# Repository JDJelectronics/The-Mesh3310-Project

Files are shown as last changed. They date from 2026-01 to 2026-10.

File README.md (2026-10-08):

# The-Mesh3310-Project
Make the world's strongest node.

## 📱 Mesh3310: The Ultimate Off-Grid Communicator
Mesh3310 is an open-source hardware project that revives the legendary Nokia 3310 (Classic). It replaces the obsolete 2G internals with a modern, high-performance PCB.

The goal is to turn this indestructible icon into a rugged, long-range mesh networking node that runs **Meshtastic** and **MeshCore**.

<p align="center">
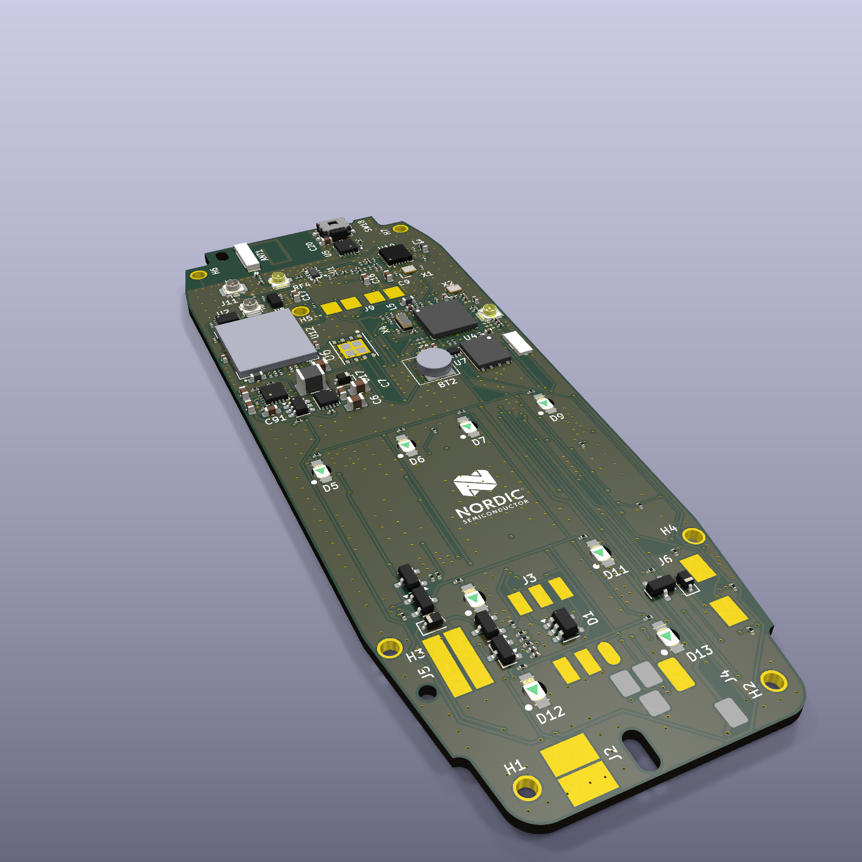
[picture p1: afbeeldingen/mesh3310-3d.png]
Mesh3310 PCB, 3D view
  
</p>

## 🚀 The Vision
The Nokia 3310 is famous for its durability, tactile keypad and ergonomic design. Our custom board drops straight into the original housing and gives the phone a second life as a decentralized communicator that does not rely on cell towers or the internet. When a network *is* available, the built-in LTE modem can connect the mesh to the rest of the world.

## ⚡ Key Specifications
| Function | Part |
|---|---|
| MCU | Nordic **nRF52840** (Cortex-M4F, Bluetooth LE, USB) |
| LoRa | Semtech **SX1262** with a Skyworks SKY65723 front-end; on-board chip antenna in the original antenna area |
| Cellular / GNSS | Nordic **nRF9151** (LTE-M / NB-IoT, DECT NR+, GNSS); antennas via U.FL |
| Bluetooth antenna | On-board 2.4 GHz chip antenna |
| Power | TI BQ24074 charger + TPS63031 buck-boost, original 3310 battery contacts |
| Charging / USB | Through the original bottom connector (USB data to the nRF52840) |
| Display / input | Original PCD8544 monochrome LCD, full keypad with backlight, side power button |
| Audio | MAX98357A amplifier for the speaker, microphone, buzzer and vibration motor contacts |
| Storage | 2 × 16 Mbit flash (MX25R1635F), one for each Nordic chip |
| Firmware | Built to run Meshtastic and MeshCore |

## 🛠 Project Status: Rev. A layout complete 🏗️
- The schematic is complete and passes ERC.
- The **6-layer PCB** (JLCPCB stackup JLC06161H-3313) is fully routed, passes DRC and matches the schematic.
- Board outline, mounting holes, battery contacts, display, SIM, speakers, keypad and backlight LEDs match the original Nokia 3310 housing.
- Controlled-impedance RF lines (50 Ω) and a solid ground plane under all three radios.
- Every assembled part has an **LCSC part number**, ready for JLCPCB assembly.

Next steps: order the first prototypes, tune the RF matching networks and start firmware bring-up.

| Top | Bottom (keypad side) |
|---|---|
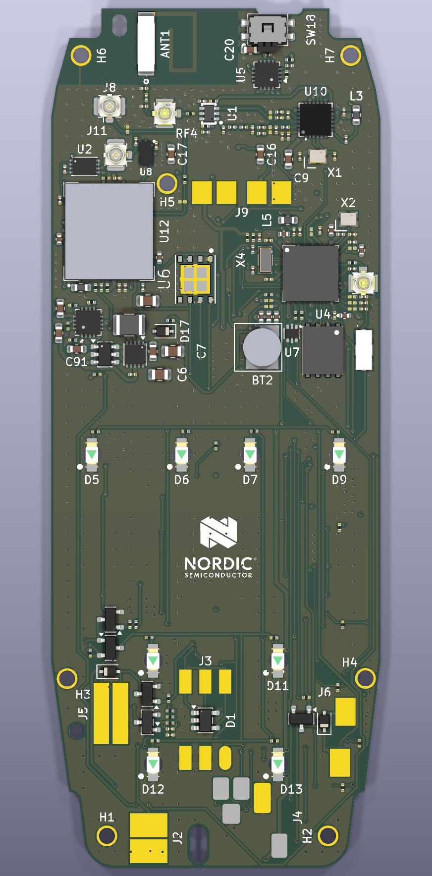
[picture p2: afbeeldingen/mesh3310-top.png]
Top side
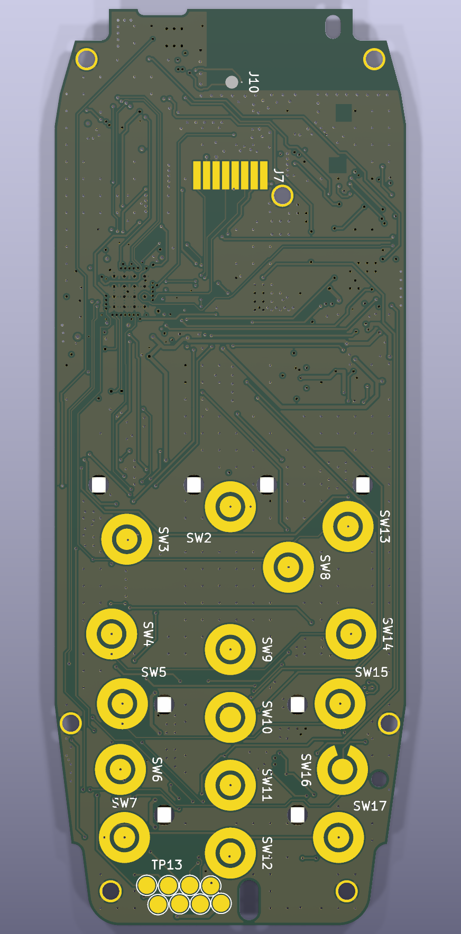
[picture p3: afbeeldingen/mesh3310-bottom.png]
Bottom side
|  |  |

## 📂 Repository Layout
| Folder | Contents |
|---|---|
| `Kicad_Mesh3310/` | KiCad 9 project (schematic, PCB, libraries, 3D models) |
| `Kicad_Mesh3310/datasheets/` | Datasheets of the main components |
| `productie/` | Gerbers, drill files, pick-and-place file and BOM (JLCPCB format), plus manufacturing notes (Dutch) |
| `afbeeldingen/` | Renders of the board |

## 🤝 How You Can Help
We are actively looking for contributors. Your input can directly shape the hardware.

- **Hardware engineering**: review the schematic and layout, and help with RF tuning.
- **Firmware development**: port Meshtastic/MeshCore to the legacy LCD and keypad matrix.
- **Mechanical design**: check the fit in original and replacement shells, and design internal 3D-printed parts.

## 💬 Community & Contributing
Most of the coordination happens on Discord.

Join our Discord: https://discord.gg/E6Sk9hmUE

### Concept images
Schermafbeelding 2026-02-24 191950



## License
MIT

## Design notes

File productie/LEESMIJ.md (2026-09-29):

# Mesh3310 — productie-opmerkingen (rev. A, 29-09-2026)

## Bestellen bij JLCPCB
- **6 lagen, opbouw JLC06161H-3313**, 1,6 mm, ENIG.
  | Laag | Functie |
  |---|---|
  | F.Cu | onderdelen, RF (50 Ω CPWG: 0,14 mm spoor, 0,30 mm spleet) |
  | In1 | doorlopend GND (referentie RF, 0,0994 mm onder F.Cu) |
  | In2 | signalen |
  | In3 | doorlopend +3V3-vlak |
  | In4 | signalen |
  | B.Cu | toetsenbord, displayconnector, GND-vulling |
- **Impedantiecontrole** aanvragen: 50 Ω enkelzijdig op F.Cu (ref. In1), 90 Ω differentieel USB (0,15/0,12 mm).
- **Via-in-pad gevuld en afgedekt (POFV/epoxy + cap)** is nodig: via's in de toets-middenpads (contactvlak onder de rubberen dome), in binnenste nRF52840-pads (aQFN-73) en in enkele kleine GND-pads.
- Kleinste maten: spoor/ruimte 0,10 mm (aQFN-uitlopen, enkele segmenten), via 0,30/0,15 mm (14 stuks), meestal 0,45/0,25 mm.

## Bestanden
- `gerber/` — 13 lagen + PTH/NPTH-boorbestanden + boorkaart + job-bestand
- `Mesh3310-positie.csv` — positiebestand (zonder DNP)
- `Mesh3310-stuklijst.csv` — stuklijst in JLC-formaat (Comment, Designator, Footprint, LCSC), zonder DNP

Opnieuw maken: exporteer vanuit KiCad 9 (Plot + Drill Files, Position Files en Bill of Materials).

## Onderdelen (LCSC)
- Alle geplaatste onderdelen hebben een LCSC-nummer (veld `LCSC` in het schema). Zonder nummer: alleen pads/behuizingsdelen (SIM J3, J4, testpunten) en BT2.
- Keuze: op voorraad (≥ 500), dan basic > preferred > extended, dan de laagste prijs. 12 basic en 72 extended soorten; onderdelen ~$46 per bord (vooral nRF9151 $17 en nRF52840 $6). Elk extended-onderdeel kost bij JLC ~$3 laadkosten per order; de meeste zijn 0201-passieven (die zijn bij JLC nooit basic).
- **Weinig voorraad** (vóór bestellen checken): SW18 C128539 (27 st.), U8 SKY65723 C2654196 (~330), U3 BQ24074 C54313 (~440), C77 C881877 (~875).
- **BT2** (ML414H knoopcel-accu) staat niet in de stuklijst (`in_bom no`) en is niet bij LCSC te krijgen; zelf plaatsen of weglaten (voedt alleen P0.26).
- Aangepast: C16/C17 van tantaal naar keramisch 0603 (C19702 10 µF, C59461 22 µF); X4 32,768 kHz met 9 pF laadcapaciteit (C97605), past bij C22/C29 van 15 pF.
- Datasheets van alle actieve en bijzondere onderdelen: `Kicad_Mesh3310/datasheets/` (van de nRF9151 alleen de productbrief; de volledige specificatie staat op docs.nordicsemi.com).

## Controle
- ERC: 0 fouten. DRC: 0 fouten, 0 onverbonden, pariteit schema ↔ bord 0.
- Nagelopen: voedings- en signaalverbindingen in de netlijst, behuizingsonderdelen en bordrand ongewijzigd t.o.v. main, GND- en +3V3-vlak doorlopend, RF-sporen zonder via's, voedingssporen ≥ 0,4 mm.
- Bewuste uitzonderingen (in `Mesh3310.kicad_dru` / projectbestand, met toelichting):
  ANT1-antennepatroon (netloos koper), BLE-antennepin nRF52840 (0,15 mm bij de pin),
  testmal-testpunten (courtyards), backlight-LED's in eigen uitsparing, aangepaste footprints (waarschuwing).

## Programmeren
- nRF52840: SWD via de testpunten van de testmal (SWDIO/SWDCLK/RESET/SWO).
- nRF9151: R10/R28 (0R naar de gedeelde SWD-lijnen) zijn standaard **niet geplaatst**. Twee SWD-chips op dezelfde lijnen werkt niet; de nRF9151 programmeren via de pads van R10/R28 (kant U12) of de 0R's tijdelijk plaatsen.

## Nog te doen / aandachtspunten
- **RF afstemmen** met de echte antennes en kabels: LTE-pi-netwerk R61/C93/C94 (shunts nu DNP), LoRa en BLE volgens het oorspronkelijke ontwerp.
- **LTE-antenne**: plak-flexantenne via U.FL J8 (bv. Taoglas FXUB63); GNSS-antenne via U.FL J11.
- **Montagegat H6** ligt in de LoRa-antennezone en is aan GND gehangen (kort spoor langs de zonerand); eventueel los laten na meting.
- **Bouwhoogte** van U.FL-connectoren J8/J11 (+ stekker) controleren in de behuizing.
- Referenties van kleine passieven staan niet op de zeefdruk (wel op de Fab-laag / in het positiebestand).

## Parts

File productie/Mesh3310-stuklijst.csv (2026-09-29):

Comment | Designator | Footprint | LCSC
0868AT43A0020E | ANT1 | mesh3310_footprints:XCVR_0868AT43A0020E | C3284550
2450AT42E0100001E | ANT2 | mesh3310_footprints:2450AT42E0100001E | C17605137
1uF | C9 | Capacitor_SMD:C_0603_1608Metric | C15849
33pF | C15 | Capacitor_SMD:C_0201_0603Metric | C384825
22uF/6.3V | C17 | Capacitor_SMD:C_0603_1608Metric | C59461
470nF | C19 | Capacitor_SMD:C_0201_0603Metric | C7393835
47uF/6.3V | C28 | Capacitor_SMD:C_0805_2012Metric | C16780
2.0pF | C30 | Capacitor_SMD:C_0201_0603Metric | C301906
1uF | C36 | Capacitor_SMD:C_0402_1005Metric | C52923
100pF | C45 | Capacitor_SMD:C_0201_0603Metric | C62550
820pF | C46 | Capacitor_SMD:C_0201_0603Metric | C18164584
47pF | C77 | Capacitor_SMD:C_0201_0603Metric | C881877
2.4pF | C78 | Capacitor_SMD:C_0201_0603Metric | C1853504
3pF | C81 | Capacitor_SMD:C_0201_0603Metric | C501815
5.6pF | C82 | Capacitor_SMD:C_0201_0603Metric | C526923
39pF | C83 | Capacitor_SMD:C_0201_0603Metric | C285092
1uF/25V | C89 | Capacitor_SMD:C_0603_1608Metric | C15849
100nF | C1,C13,C34,C41,C58,C69 | Capacitor_SMD:C_0201_0603Metric | C408130
15p | C11,C26 | Capacitor_SMD:C_0201_0603Metric | C5142550
10uF/10V | C16,C20,C92 | Capacitor_SMD:C_0603_1608Metric | C19702
0.1u | C2,C4,C10,C12,C33,C43 | Capacitor_SMD:C_0201_0603Metric | C408130
15pF | C22,C29 | Capacitor_SMD:C_0201_0603Metric | C5142550
4.7u | C3,C8 | Capacitor_SMD:C_0402_1005Metric | C23733
12pF | C31,C32 | Capacitor_SMD:C_0201_0603Metric | C50391
2.2uF | C35,C37,C39,C40,C47,C50 | Capacitor_SMD:C_0402_1005Metric | C107370
47nF | C38,C76 | Capacitor_SMD:C_0201_0603Metric | C301920
100n | C5,C14,C18,C21,C27 | Capacitor_SMD:C_0201_0603Metric | C408130
22uF/10V | C6,C7 | Capacitor_SMD:C_0805_2012Metric | C45783
10pF | C70,C71 | Capacitor_SMD:C_0201_0603Metric | C387913
1.8pF | C75,C84 | Capacitor_SMD:C_0201_0603Metric | C22374841
1nF | C85,C86 | Capacitor_SMD:C_0201_0603Metric | C66942
3.6pF | C87,C88 | Capacitor_SMD:C_0201_0603Metric | C301911
4.7uF/10V | C90,C91 | Capacitor_SMD:C_0603_1608Metric | C19666
SP0504BAHT | D1 | Package_TO_SOT_SMD:SOT-23-5 | C19829475
BAT60A | D4,D8,D17 | Diode_SMD:D_SOD-323 | C5355496
RED | D5,D6,D7,D9,D10,D11,D12,D13 | mesh3310_footprints:3310_led | C2827254
120R@100MHz 1A | FB1 | Inductor_SMD:L_0603_1608Metric | C14709
Sim/Pad | J3 | mesh3310_footprints:3310_sim
Conn_01x05_Pin | J4 | mesh3310_footprints:3310_dc
LTE antenne: U.FL -> flexantenne (bv. Taoglas FXUB63) | J8 | Connector_Coaxial:U.FL_Hirose_U.FL-R-SMT-1_Vertical | C88374
GNSS antenne (U.FL) | J11 | Connector_Coaxial:U.FL_Hirose_U.FL-R-SMT-1_Vertical | C88374
3.3nH | L1 | Inductor_SMD:L_0201_0603Metric | C42144
1u5 | L2 | Inductor_SMD:L_1210_3225Metric | C113080
15uH | L3 | Inductor_SMD:L_0603_1608Metric | C486329
1.5nH | L4 | Inductor_SMD:L_0201_0603Metric | C54929554
10uH | L5 | Inductor_SMD:L_0603_1608Metric | C1035
0 | L15 | Inductor_SMD:L_0201_0603Metric | C473473
47nH | L16 | Inductor_SMD:L_0201_0603Metric | C46607399
2.5nH | L17 | Inductor_SMD:L_0201_0603Metric | C52109745
4.7nH | L18 | Inductor_SMD:L_0201_0603Metric | C52109761
8.2nH | L19 | Inductor_SMD:L_0201_0603Metric | C52109772
15nH | L6,L13 | Inductor_SMD:L_0201_0603Metric | C52109780
BC847 | Q1 | Package_TO_SOT_SMD:SOT-23 | C57668
IRLML6401 | Q6 | Package_TO_SOT_SMD:SOT-23 | C22363750
BSS138 | Q4,Q5,Q7 | Package_TO_SOT_SMD:SOT-23 | C518792
1.8k | R5 | Resistor_SMD:R_0201_0603Metric | C473538
33R | R8 | Resistor_SMD:R_0201_0603Metric | C423356
2.2k | R9 | Resistor_SMD:R_0201_0603Metric | C171950
1M | R14 | Resistor_SMD:R_0201_0603Metric | C473450
56R | R16 | Resistor_SMD:R_0201_0603Metric | C49654370
220k | R36 | Resistor_SMD:R_0201_0603Metric | C49653410
100k | R15,R17,R20,R37,R51 | Resistor_SMD:R_0201_0603Metric | C3152012
47k | R18,R31,R32,R33,R34,R35,R59,R60 | Resistor_SMD:R_0201_0603Metric | C304544
150R | R19,R21,R22,R23,R24,R25,R26,R27 | Resistor_SMD:R_0201_0603Metric | C49653085
0 | R3,R38,R57,R58 | Resistor_SMD:R_0201_0603Metric | C473473
1k | R4,R13,R29,R52 | Resistor_SMD:R_0201_0603Metric | C3152043
100 | R44,R45 | Resistor_SMD:R_0201_0603Metric | C3152013
0R | R6,R61 | Resistor_SMD:R_0201_0603Metric | C473473
10k | R7,R11,R12,R30 | Resistor_SMD:R_0201_0603Metric | C3152038
A-IPEX1-1.25A | RF3,RF4 | mesh3310_footprints:IPEX-SMD_3P-L2.6-W2.6-LS3.0_RF1200001R | C22467595
POWER ON/OFF | SW18 | mesh3310_footprints:SIDE PUSH 2.2NF 4.7x3.2x1.65mm | C128539
VBUS | TP9 | TestPoint:TestPoint_Pad_D2.0mm
GND | TP10 | TestPoint:TestPoint_Pad_D2.0mm
USB_D- | TP11 | TestPoint:TestPoint_Pad_D2.0mm
USB_D+ | TP12 | TestPoint:TestPoint_Pad_D2.0mm
TPE4259-63 | U1 | mesh3310_footprints:SOT-363-6_L2.0-W1.3-P0.65-LS2.1-BL | C47117600
MX25R1635FZUIH0 | U2 | Package_SON:Winbond_USON-8-1EP_3x2mm_P0.5mm_EP0.2x1.6mm | C5687033
BQ24074RGT | U3 | Package_DFN_QFN:VQFN-16-1EP_3x3mm_P0.5mm_EP1.6x1.6mm | C54313
MX25R1635FZNIH0 | U4 | mesh3310_footprints:SON127P500X600X80-9N | C6930062
MAX98357A | U5 | Package_DFN_QFN:TQFN-16-1EP_3x3mm_P0.5mm_EP1.23x1.23mm | C910544
USBLC6-2P6 | U7 | Package_TO_SOT_SMD:SOT-666 | C22390016
SKY65723-81 | U8 | mesh3310_footprints:SKY65723-81 | C2654196
MAX16054 | U9 | Package_TO_SOT_SMD:TSOT-23-6 | C79401
SX1262IMLTRT | U10 | mesh3310_footprints:QFN-24_L4.0-W4.0-P0.50-BL-EP2.6 | C191341
nRF9151-LAXX | U12 | mesh3310_footprints:XCVR_NRF9151-LACA-R7 | C42236596
NRF52840-QIAA-R | U13 | mesh3310_footprints:XCVR_NRF52840-QIAA-R | C190794
TPS63031DSK | U14 | Package_SON:WSON-10-1EP_2.5x2.5mm_P0.5mm_EP1.2x2mm | C15516
32.768KHz | X4 | Crystal:Crystal_SMD_3215-2Pin_3.2x1.5mm | C97605
S201632M10PF10PPM 32MHz | X1,X2 | mesh3310_footprints:CRYSTAL-SMD_4P-L2.0-W1.6-BL | C7420782

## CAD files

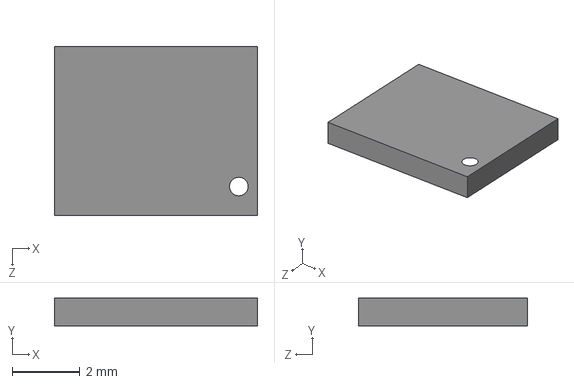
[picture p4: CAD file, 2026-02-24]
Kicad_Mesh3310/3D_models/SIM-ST-MFF2.step
6.00 x 0.82 x 5.00 mm

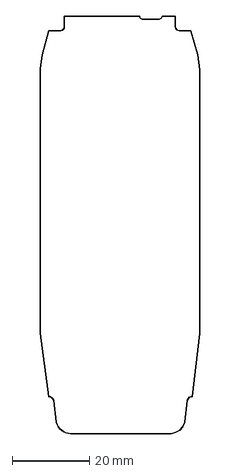
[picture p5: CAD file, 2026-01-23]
Kicad_Mesh3310/misc/3310_outline.dxf
41.4 x 108.0 mm

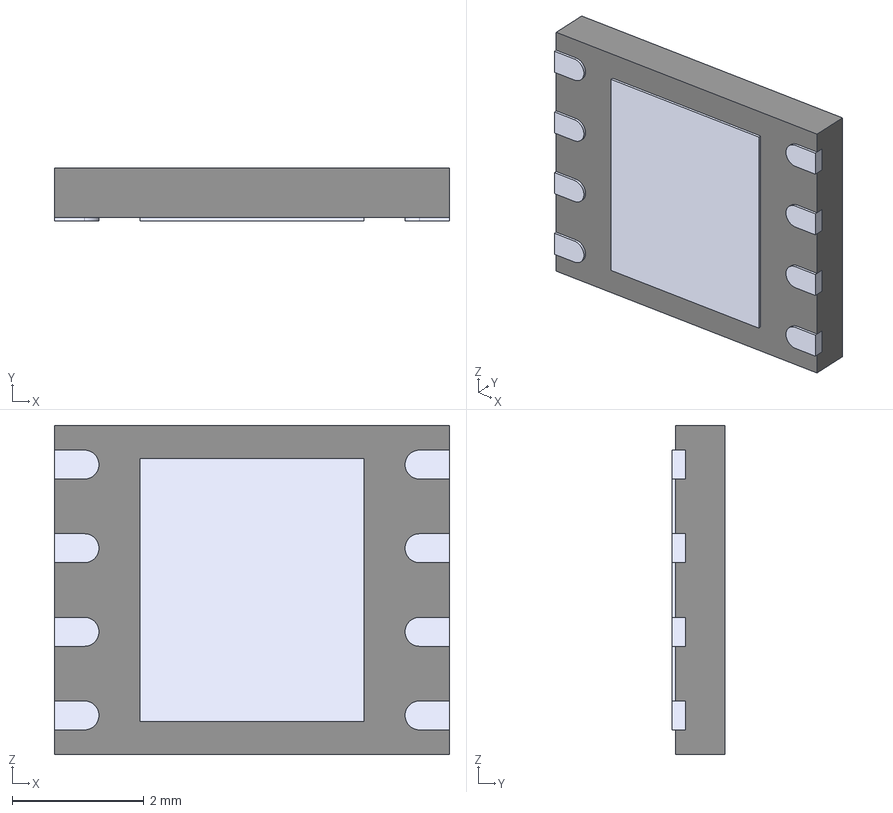
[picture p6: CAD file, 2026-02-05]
Kicad_Mesh3310/3D_models/MX25R1635FZNIH0.step
6.00 x 0.8 x 5.00 mm
Body_Solid1
Body002_Solid1
Array002_Solid1 x 4
Array003_Solid2 x 3
Body003_Solid1
Body004_Solid1
Pad004_Solid1

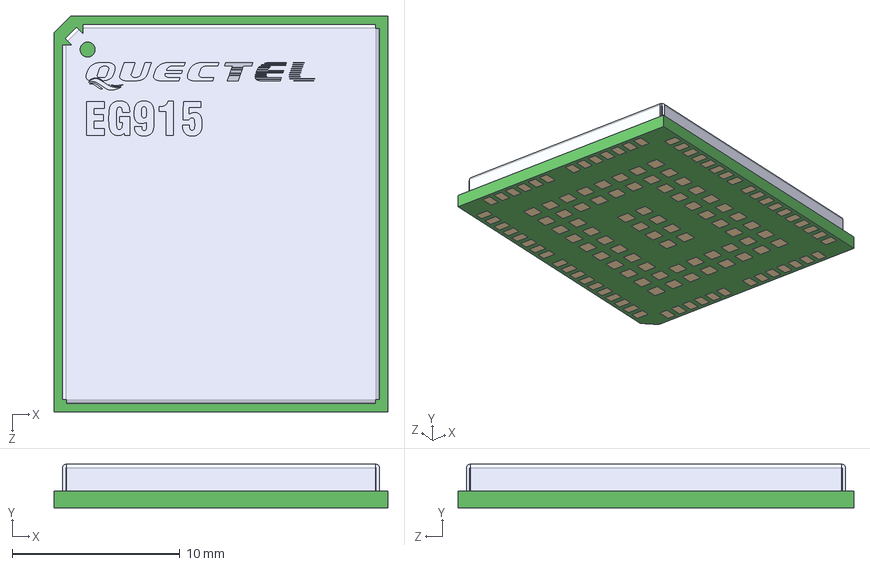
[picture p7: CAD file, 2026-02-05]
Kicad_Mesh3310/3D_models/EG915UEUAC-N05-SNNSA.step
19.9 x 2.60 x 23.6 mm

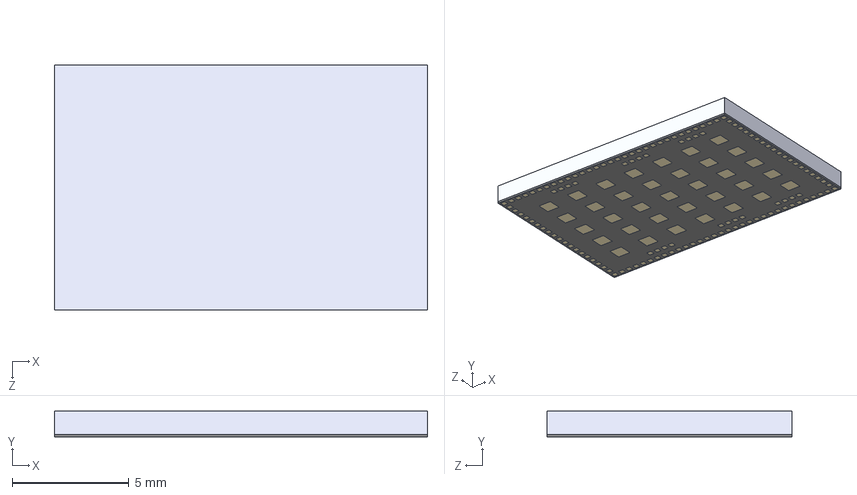
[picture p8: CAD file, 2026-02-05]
Kicad_Mesh3310/3D_models/NRF9160-SIBA-R.step
16.0 x 1.10 x 10.5 mm

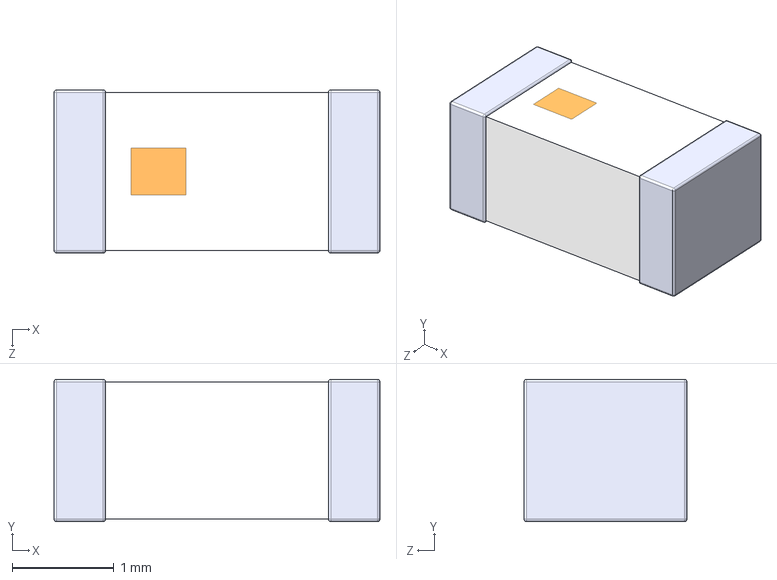
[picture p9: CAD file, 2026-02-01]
Kicad_Mesh3310/3D_models/2450AT18A0100001E.step
3.20 x 1.40 x 1.60 mm

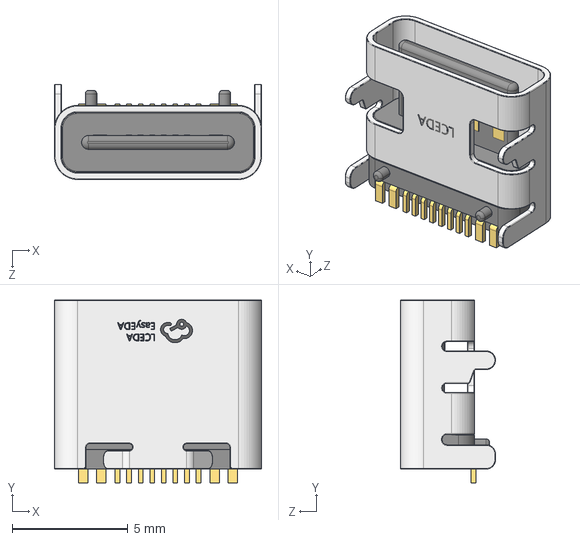
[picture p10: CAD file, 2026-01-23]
Kicad_Mesh3310/3D_models/USB-C_SMD-TYPE-C-31-M-12_1.step
8.94 x 7.90 x 4.10 mm

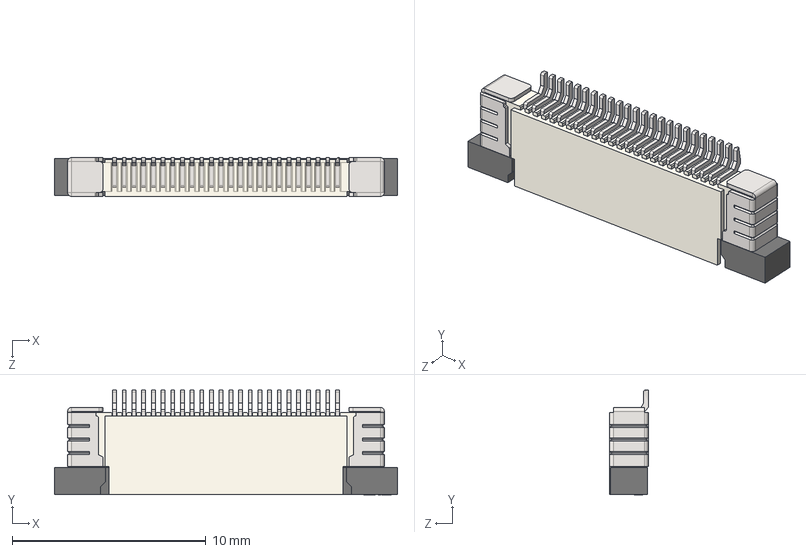
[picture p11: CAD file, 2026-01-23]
Kicad_Mesh3310/3D_models/FPC-SMD_XUNPU_FPC-0.5AS-24PWBH20.step
17.7 x 5.41 x 2.00 mm

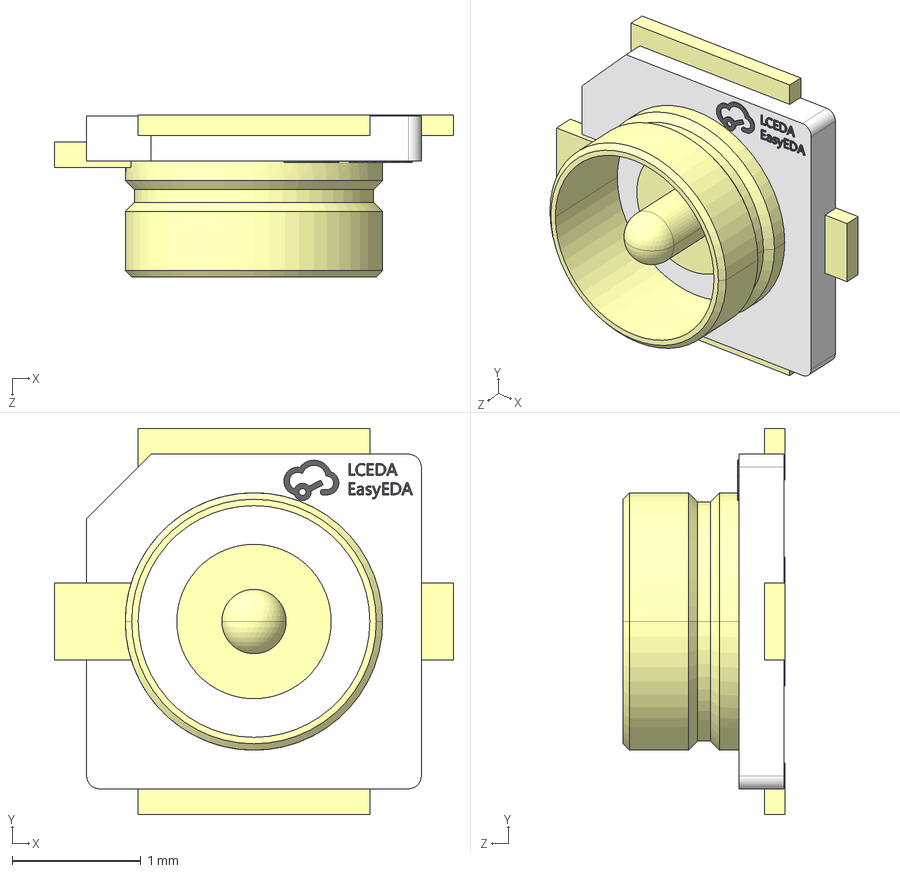
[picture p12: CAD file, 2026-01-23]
Kicad_Mesh3310/3D_models/IPEX-SMD_3P-L2.6-W2.6-LS3.0_RF1200001R.step
3.10 x 3.00 x 1.26 mm

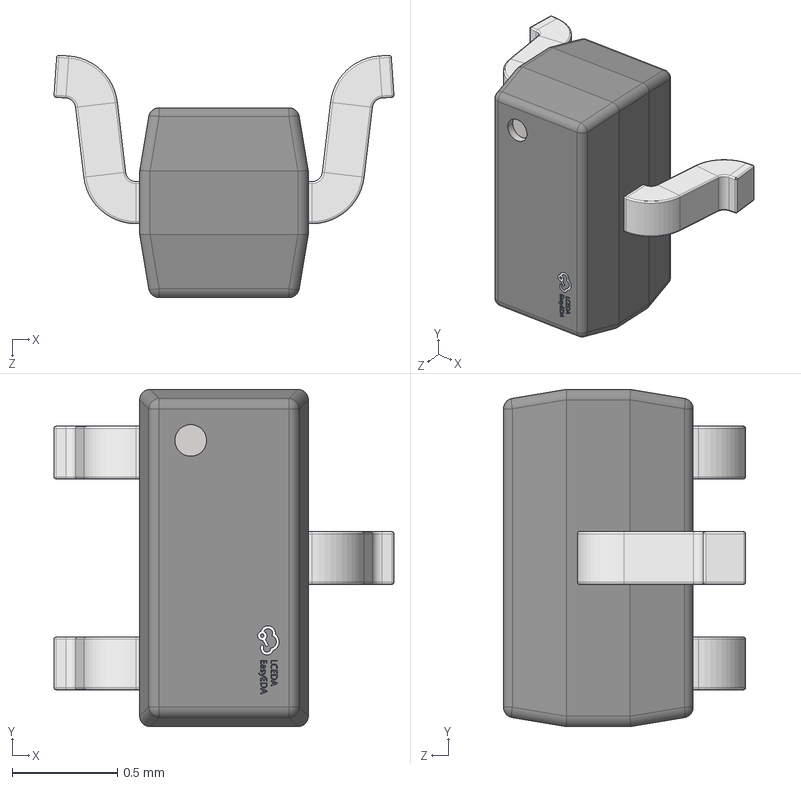
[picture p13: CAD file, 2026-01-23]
Kicad_Mesh3310/3D_models/SOT-523-3P_L1.6-W0.8-H0.9-LS1.6-P0.50.step
1.61 x 1.60 x 1.15 mm

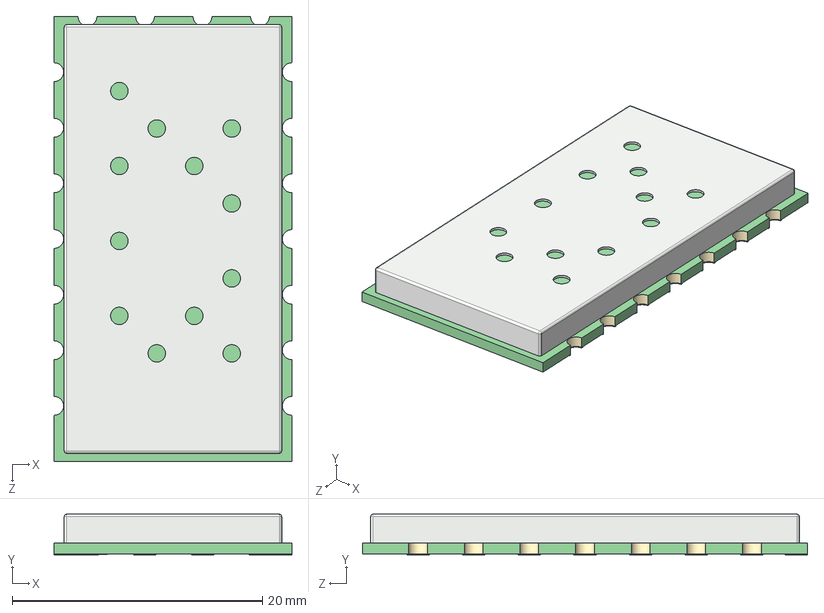
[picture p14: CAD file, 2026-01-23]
Kicad_Mesh3310/3D_models/sa868.step
19.0 x 3.26 x 35.6 mm

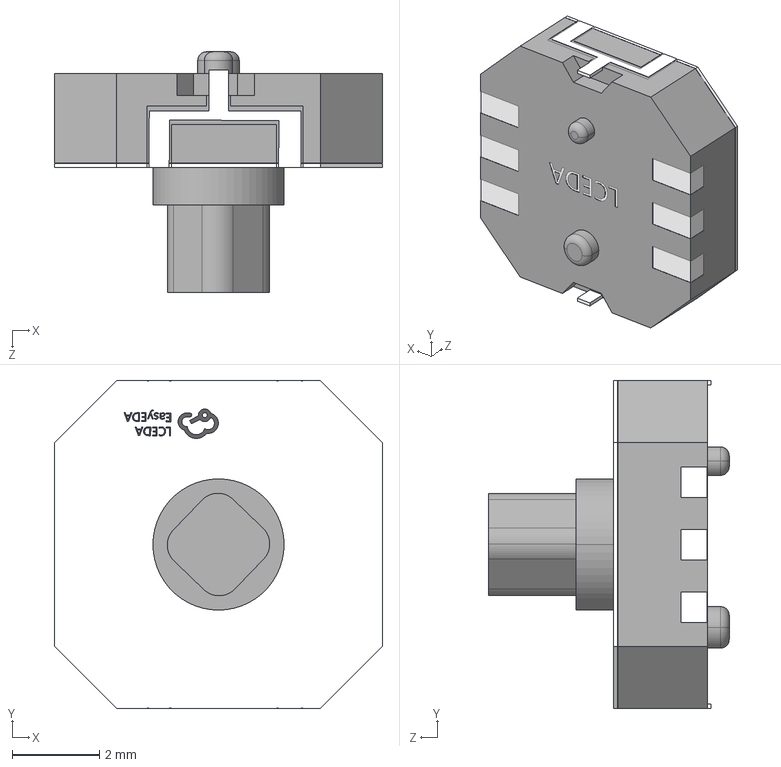
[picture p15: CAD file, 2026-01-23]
Kicad_Mesh3310/3D_models/SW-SMD_SKRHABE010.step
7.50 x 7.50 x 5.50 mm

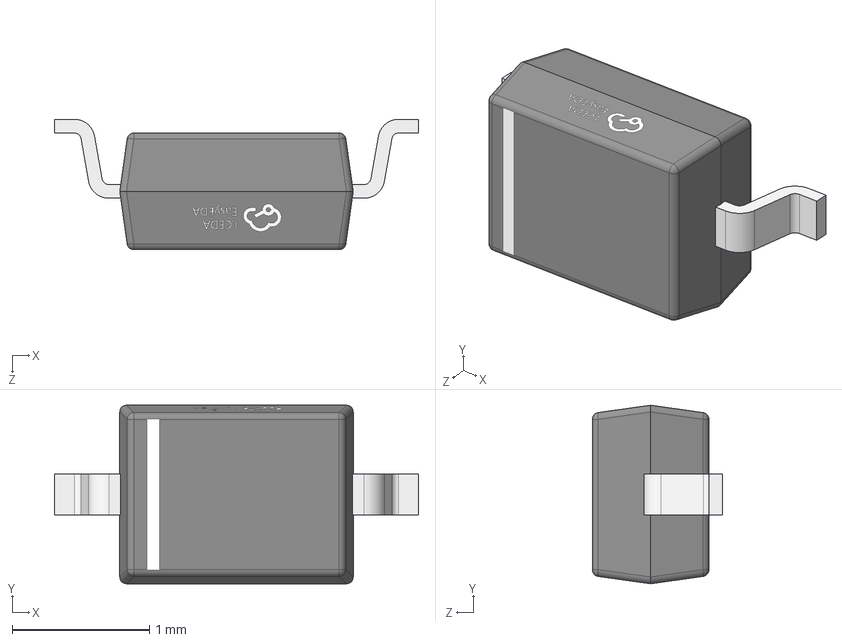
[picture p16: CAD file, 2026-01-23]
Kicad_Mesh3310/3D_models/SOD-323_L1.8-W1.3-LS2.5-RD.step
2.65 x 1.30 x 0.95 mm

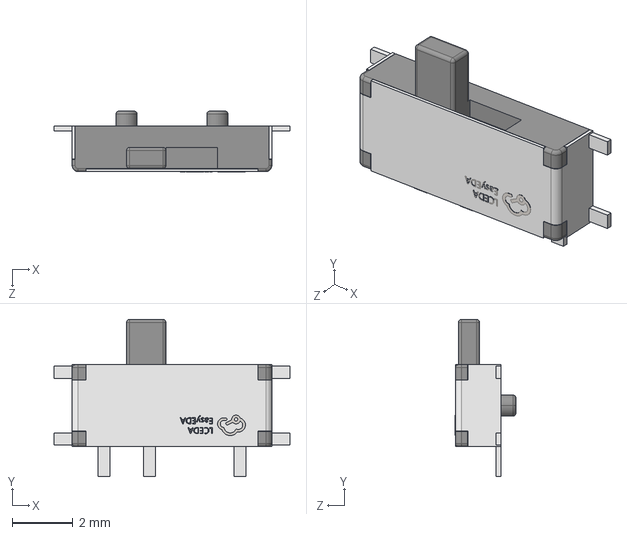
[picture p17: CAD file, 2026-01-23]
Kicad_Mesh3310/3D_models/SW-SMD_3P-L6.6-W2.7-LS7.8-P1.50.step
7.80 x 5.20 x 2.01 mm

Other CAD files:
Kicad_Mesh3310/3D_models/FPC-SMD_FH12-24S-0.5SH-55.step
Kicad_Mesh3310/3D_models/RA-01H--3DModel-STEP-1.STEP
Kicad_Mesh3310/3D_models/SOIC-8_L4.9-W3.9-H1.7-LS6.0-P1.27.step
Kicad_Mesh3310/3D_models/VSON-14_L4.0-W3.0-H1.0-P0.50.step
Kicad_Mesh3310/3D_models/AQFN-73_L7.0-W7.0-H0.9-P0.50.step
Kicad_Mesh3310/3D_models/BUZ-SMD_4P-L8.5-W8.5-H3.0.step
Kicad_Mesh3310/3D_models/CONN-SMD_HCZZ0032-4.step
Kicad_Mesh3310/3D_models/CONN-SMD_PH-2AWB.step
Kicad_Mesh3310/3D_models/CONN-SMD_ZH1.5-WS-2P.step
Kicad_Mesh3310/3D_models/CRYSTAL-SMD_4P-L2.0-W1.6-BL.step
Kicad_Mesh3310/3D_models/FC-135R_L3.2-W1.5.step
Kicad_Mesh3310/3D_models/FILTER-SMD_10P-L2.0-W1.3-H1.0-P0.5.step
Kicad_Mesh3310/3D_models/IND-SMD_L4.2-W4.4-H2.0.step
Kicad_Mesh3310/3D_models/IND-SMD_L6.0-W6.0-H4.5.step
Kicad_Mesh3310/3D_models/KEY-SMD_2P-L6.0-W6.0-H5.0-P6.00.step
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

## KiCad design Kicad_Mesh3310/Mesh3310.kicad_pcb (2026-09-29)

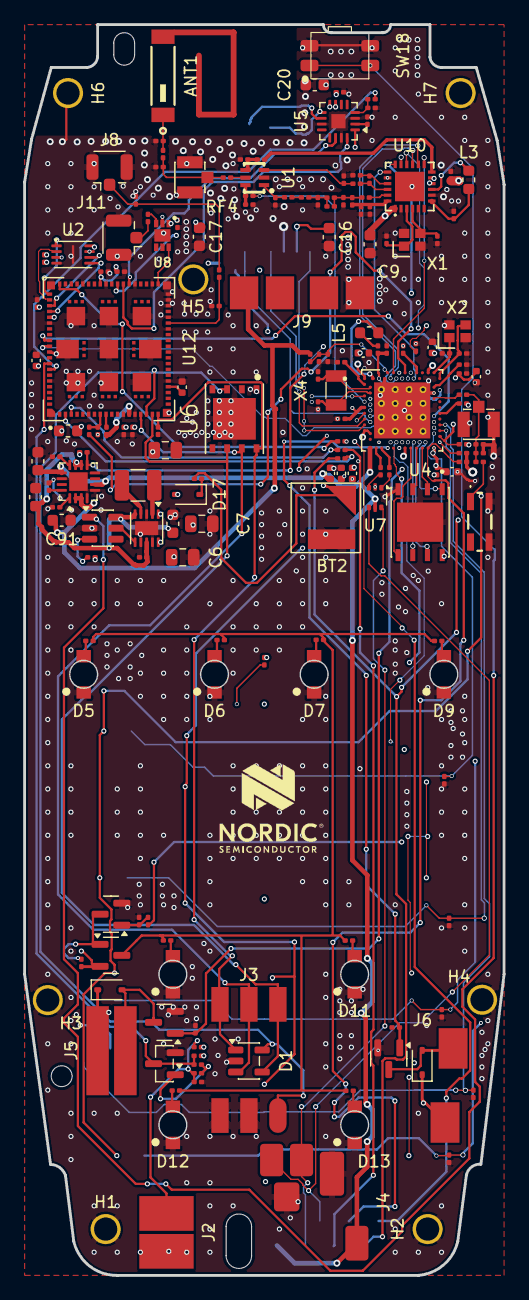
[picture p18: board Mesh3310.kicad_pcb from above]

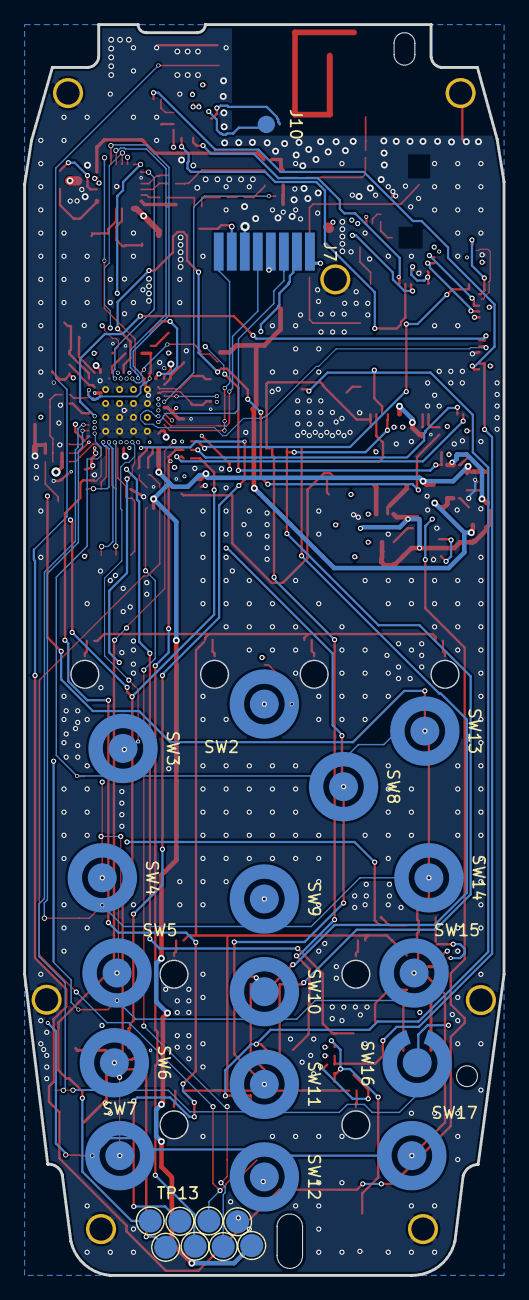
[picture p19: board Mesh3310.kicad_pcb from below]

Board: 6 copper layers, 41.4 x 108.0 mm, 211 parts (26 on the bottom side), 144 nets.

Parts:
ANT1: 0868AT43A0020E; XCVR_0868AT43A0020E
ANT2: 2450AT42E0100001E
BT2: ML414H-IV01E; ML414H
C1, C13, C34, C41, C48, C58, C69: 100nF; C_0201_0603Metric
C2, C4, C10, C12, C33, C43: 0.1u; C_0201_0603Metric
C3, C8: 4.7u; C_0402_1005Metric
C5, C14, C18, C21, C27: 100n; C_0201_0603Metric
C6, C7: 22uF/10V; C_0805_2012Metric
C9: 1uF; C_0603_1608Metric
C11, C26: 15p; C_0201_0603Metric
C15: 33pF; C_0201_0603Metric
C16, C20, C92: 10uF/10V; C_0603_1608Metric
C17: 22uF/6.3V; C_0603_1608Metric
C19: 470nF; C_0201_0603Metric
C22, C29: 15pF; C_0201_0603Metric
C28: 47uF/6.3V; C_0805_2012Metric
C30: 2.0pF; C_0201_0603Metric
C31, C32: 12pF; C_0201_0603Metric
C35, C37, C39, C40, C47, C50: 2.2uF; C_0402_1005Metric
C36: 1uF; C_0402_1005Metric
C38, C76: 47nF; C_0201_0603Metric
C45, C49: 100pF; C_0201_0603Metric
C46: 820pF; C_0201_0603Metric
C70, C71: 10pF; C_0201_0603Metric
C75, C84: 1.8pF; C_0201_0603Metric
C77: 47pF; C_0201_0603Metric
C78: 2.4pF; C_0201_0603Metric
C79, C80: NC; C_0201_0603Metric
C81: 3pF; C_0201_0603Metric
C82: 5.6pF; C_0201_0603Metric
C83: 39pF; C_0201_0603Metric
C85, C86: 1nF; C_0201_0603Metric
C87, C88: 3.6pF; C_0201_0603Metric
C89: 1uF/25V; C_0603_1608Metric
C90, C91: 4.7uF/10V; C_0603_1608Metric
C93, C94: NC (afstemmen); C_0201_0603Metric
D1: SP0504BAHT; SOT-23-5
D4, D8, D17: BAT60A; D_SOD-323
D5, D6, D7, D9, D10, D11, D12, D13: RED; 3310_led
FB1: 120R@100MHz 1A; L_0603_1608Metric
H1, H2, H3, H4, H5, H6, H7: 2mm_mounting_hole_sig
J2: Mic pad; 3310_mic
J3: Sim/Pad; 3310_sim
J4: Conn_01x05_Pin; 3310_dc
J5: Vibrator pad; 3310_vibrator
J6: Buzzer pad; 3310_buzzer
J7: Display; 3310_display
J8: LTE antenne: U.FL -> flexantenne (bv. Taoglas FXU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; U.FL_Hirose_U.FL-R-SMT-1_Vertical
J9: Battery; 3310_batt
J10: Speaker pad; 3310_earspeaker
J11: GNSS antenne (U.FL); U.FL_Hirose_U.FL-R-SMT-1_Vertical
L1: 3.3nH; L_0201_0603Metric
L2: 1u5; L_1210_3225Metric
L3: 15uH; L_0603_1608Metric
L4: 1.5nH; L_0201_0603Metric
L5: 10uH; L_0603_1608Metric
L6, L13: 15nH; L_0201_0603Metric
L15: 0; L_0201_0603Metric
L16: 47nH; L_0201_0603Metric
L17: 2.5nH; L_0201_0603Metric
L18: 4.7nH; L_0201_0603Metric
L19: 8.2nH; L_0201_0603Metric
NT3: NetTie_2; NetTie-2_SMD_Pad0.5mm
Q1: BC847; SOT-23
Q4, Q5, Q7: BSS138; SOT-23
Q6: IRLML6401; SOT-23
R3, R10, R28, R38, R57, R58: 0; R_0201_0603Metric
R4, R13, R29, R52: 1k; R_0201_0603Metric
R5: 1.8k; R_0201_0603Metric
R6, R61: 0R; R_0201_0603Metric
R7, R11, R12, R30, R49, R50, R55: 10k; R_0201_0603Metric
R8: 33R; R_0201_0603Metric
R9: 2.2k; R_0201_0603Metric
R14: 1M; R_0201_0603Metric
R15, R17, R20, R37, R51: 100k; R_0201_0603Metric
R16: 56R; R_0201_0603Metric
R18, R31, R32, R33, R34, R35, R59, R60: 47k; R_0201_0603Metric
R19, R21, R22, R23, R24, R25, R26, R27: 150R; R_0201_0603Metric
R36: 220k; R_0201_0603Metric
R44, R45: 100; R_0201_0603Metric
RF3, RF4: A-IPEX1-1.25A; IPEX-SMD_3P-L2.6-W2.6-LS3.0_RF1200001R
SW2: "OK"; 3310_key
SW3, SW4, SW5, SW6, SW7, SW8, SW9, SW10, SW11, SW12, SW13, SW14, SW15, SW17: 3310_key
SW16: 3310_key_gap
SW18: POWER ON/OFF; SIDE PUSH 2.2NF 4.7x3.2x1.65mm
TP6: SWDIO; TestPoint_Pad_D2.0mm
TP7: SWO; TestPoint_Pad_D2.0mm
TP8: SWDCLK; TestPoint_Pad_D2.0mm
TP9: VBUS; TestPoint_Pad_D2.0mm
TP10: GND; TestPoint_Pad_D2.0mm
TP11: USB_D-; TestPoint_Pad_D2.0mm
TP12: USB_D+; TestPoint_Pad_D2.0mm
TP13: RESET; TestPoint_Pad_D2.0mm
U1: TPE4259-63; SOT-363-6_L2.0-W1.3-P0.65-LS2.1-BL
U2: MX25R1635FZUIH0; Winbond_USON-8-1EP_3x2mm_P0.5mm_EP0.2x1.6mm
U3: BQ24074RGT; VQFN-16-1EP_3x3mm_P0.5mm_EP1.6x1.6mm
U4: MX25R1635FZNIH0; SON127P500X600X80-9N
U5: MAX98357A; TQFN-16-1EP_3x3mm_P0.5mm_EP1.23x1.23mm
U6: SIM-ST-MFF2; PSON127P500X600X82-9N
U7: USBLC6-2P6; SOT-666
U8: SKY65723-81
U9: MAX16054; TSOT-23-6
U10: SX1262IMLTRT; QFN-24_L4.0-W4.0-P0.50-BL-EP2.6
U12: nRF9151-LAXX; XCVR_NRF9151-LACA-R7
U13: NRF52840-QIAA-R; XCVR_NRF52840-QIAA-R
U14: TPS63031DSK; WSON-10-1EP_2.5x2.5mm_P0.5mm_EP1.2x2mm
X1, X2: S201632M10PF10PPM 32MHz; CRYSTAL-SMD_4P-L2.0-W1.6-BL
X4: 32.768KHz; Crystal_SMD_3215-2Pin_3.2x1.5mm

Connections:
+3V3: C2.1, C3.1, C6.1, C7.1, C9.1, C13.1, C17.1, C18.2, C20.2, C26.1, C28.1, C33.1, C34.1, C35.1, C37.1, C39.1, C40.1, C43.1, C58.1, C69.2, D4.1 (K), D8.1 (K), D17.2 (A), FB1.1, J5.1, J6.1, J7.8, Q6.2 (S), R8.2, R9.2, R11.2, R18.2, R30.2, R49.2, R50.2, U2.3, U2.7, U2.8, U4.8 (VCC), U5.7 (VDD), U5.8 (VDD), U8.1 (VCC), U10.1 (VDD_IN), U10.10 (VBAT), U10.11 (VBAT_IO), U12.65 (VDD_GPIO), U13.A22 (VDD), U13.AD14 (VDD), U13.AD23 (VDD), U13.B1 (VDD), U13.W1 (VDD), U13.Y2 (VDDH), U14.1 (VOUT), U14.10 (FB)
/GSM/COEX0: C12.1, R14.1, U8.2 (VEN), U12.52 (COEX0)
/GSM/FLASH_CS: U2.1, U12.61 (P0.04)
/GSM/FLASH_MISO: U2.2, U12.62 (P0.05)
/GSM/FLASH_MOSI: U2.5, U12.64 (P0.07)
/GSM/FLASH_SCK: U2.6, U12.63 (P0.06)
/GSM/RF_ANT: C93.1, R61.1, U12.35 (ANT)
/GSM/RF_GPS: U8.6 (RF_OUT), U12.42 (GPS)
/GSM/RF_IN: C11.1, U8.3 (RF_IN)
/GSM/SIM_CLK: D1.4 (K), J3.3, U6.6 (CLK), U12.18 (SIM_CLK)
/GSM/SIM_IO: D1.5 (K), J3.6, U6.3 (I/O), U12.17 (SIM_IO)
/GSM/SIM_RST: D1.3 (K), J3.2, U6.7 (RST), U12.16 (SIM_RST)
/GSM/SIM_VCC: C4.1, D1.1 (K), J3.1, U6.8 (VCC), U12.19 (SIM_1V8)
/I2S_BCLK: U5.16 (BCLK), U12.48 (P0.29)
/I2S_LRCK: U5.14 (LRCLK), U12.47 (P0.28)
/I2S_SDOUT: U5.1 (DIN), U12.49 (P0.30)
/LORA/DIO2: R45.1, U10.12 (DIO2)
/LORA/XTA: C70.1, U10.3 (XTA), X1.1
/LORA/XTB: C71.1, U10.4 (XTB), X1.3
/MCU/DCC: L5.2, U13.B3 (DCC)
/MCU/DEC1: C41.2, U13.C1 (DEC1)
/MCU/DEC2: C48.2, U13.A18 (DEC2)
/MCU/DEC3: C45.2, U13.D23 (DEC3)
/MCU/DEC4: C36.2, C38.1, C49.2, L6.1, U13.B5 (DEC4), U13.E24 (DEC6)
/MCU/DEC5: C46.2, U13.N24 (DEC5)
/MCU/DECUSB: C47.1, U13.AC5 (DECUSB)
/MCU/DIODE_USB_D+: R57.2, U7.1 (I/O1)
/MCU/DIODE_USB_D-: R58.2, U7.3 (I/O2)
/MCU/NRF_USB_D+: R57.1, U13.AD6 (D+)
/MCU/NRF_USB_D-: R58.1, U13.AD4 (D-)
/MCU/P0.06: C1.1, SW2.1, U13.L1 (P0.06)
/MCU/P0.20_QSPI_SIO_0: U4.5 (SI/SIO0), U13.AD16 (P0.20)
/MCU/P0.21_QSPI_SCK: U4.6 (SCLK), U13.AC17 (P0.21)
/MCU/P0.22_QSPI_SIO_2: U4.3 (~WP/SIO2), U13.AD18 (P0.22)
/MCU/P0.23_QSPI_SIO_3: U4.7 (~RESET/SIO3), U13.AC19 (P0.23)
/MCU/P0.24_QSPI_SIO_1: U4.2 (SO/SIO1), U13.AD20 (P0.24)
/MCU/P0.25_QSPI_CSN: U4.1 (~CS), U13.AC21 (P0.25)
/MCU/P1.00_SWO: R50.1, TP7.1, U13.AD22 (P1.00/TRACEDATA0)
/MCU_RESETn: TP13.1, U13.AC13 (P0.18/NRESET)
/MIC_OUT: Q1.3 (C), R30.1, R36.2, U12.73 (P0.13/AIN0)
/P0.02_PWR_OFF: R51.2, U9.3 (CLR), U13.A12 (P0.02/AIN0)
/P0.03_LORA_MISO: U10.16 (MISO), U13.B13 (P0.03/AIN1)
/P0.04_LORA_RF_SW1: R44.1, U13.J1 (P0.04/AIN2)
/P0.05_~CHG: R11.1, U3.9 (~CHG), U13.K2 (P0.05/AIN3)
/P0.07_DSP_D/C: J7.5, U13.M2 (P0.07/TRACECLK)
/P0.08_DSP_SCK: J7.7, U13.N1 (P0.08)
/P0.11_DSP_SDIN: J7.6, U13.T2 (P0.11/TRACEDATA2)
/P0.12_DSP_RESETn: J7.1, U13.U1 (P0.12/TRACEDATA1)
/P0.13_BUZZ: Q7.1 (G), R20.2, U13.AD8 (P0.13)
/P0.14_VIBR: Q4.1 (G), R15.2, U13.AC9 (P0.14)
/P0.15_BACKLIGHT: R16.1, U13.AD10 (P0.15)
/P0.26_BAT_RTC: BT2.1 (+), R52.1, U13.G1 (P0.26)
/P0.27_GSM_WAKE: R29.1, U13.H2 (P0.27)
/P0.28_LORA_BUSY: U10.14 (BUSY), U13.B11 (P0.28/AIN4)
/P0.29_LORA_DIO1: U10.13 (DIO1), U13.A10 (P0.29/AIN5)
/P0.30_LORA_RST: U10.15 (NRESET), U13.B9 (P0.30/AIN6)
/P0.31_BAT_MEAS: C27.2, R59.1, R60.2, U13.A8 (P0.31/AIN7)
/P1.07_GSM_RX: U12.69 (P0.10), U13.P23 (P1.07)
/P1.08_GSM_TX: U12.70 (P0.11), U13.P2 (P1.08)
/P1.09_DSP_CSN: J7.4, U13.R1 (P1.09/TRACEDATA3)
/P1.12_LORA_SPI_NSS: U10.19 (NSS), U13.B17 (P1.12)
/P1.13_LORA_SCK: U10.18 (SCK), U13.A16 (P1.13)
/P1.14_LORA_MOSI: U10.17 (MOSI), U13.B15 (P1.14)
/P1.15_GSM_RESET: R13.1, U13.A14 (P1.15)
/POWER/VBAT: C91.1, J9.1, R59.2, U3.2 (BAT), U3.3 (BAT)
/POWER/VSYS: C5.2, C90.1, C92.1, U3.10 (OUT), U3.11 (OUT), U9.6 (VCC), U14.5 (VIN), U14.8 (VINA)
/SWDCLK: R10.2, R55.2, TP8.1, U13.AA24 (SWDCLK)
/SWDIO: R28.1, R49.1, TP6.1, U13.AC24 (SWDIO)
/Shutdown_Mono: R37.1, U12.74 (P0.14/AIN1)
/USB_D+: J4.4, TP12.1, U7.6 (I/O1)
/USB_D-: J4.5, TP11.1, U7.4 (I/O2)
ANT: R3.2, U13.H23 (ANT)
GND: ANT2.3 (GND_1), ANT2.4 (GND_2), BT2.2 (-), C1.2, C2.2, C3.2, C4.2, C5.1, C6.2, C7.2, C8.2, C9.2, C10.2, C12.2, C13.2, C15.1, C16.2, C17.2, C18.1, C19.2, C20.1, C21.1, C22.2, C26.2, C27.1, C28.2, C29.2, C31.1, C32.1, C33.2, C34.2, C35.2, C36.1, C37.2, C38.2, C39.2, C40.2, C41.1, C43.2, C45.1, C46.1, C47.2, C48.1, C49.1, C50.2, C58.2, C69.1, C70.2, C71.2, C75.1, C76.2, C77.2, C79.1, C80.1, C82.2, C84.2, C85.2, C86.2, C87.2, C88.2, C89.2, C90.2, C91.2, C92.2, C93.2, C94.2, D1.2 (A), D5.1 (K), D6.1 (K), D7.1 (K), D9.1 (K), D10.1 (K), D11.1 (K), D12.1 (K), D13.1 (K), H1.1, H2.1, H3.1, H4.1, H5.1, H6.1, H7.1, J2.2, J3.4, J3.5, J4.2, J4.3, J7.3, J8.2 (Ext), J9.4, J11.2, NT3.1, Q1.2 (E), Q4.2 (S), Q5.2 (S), Q7.2 (S), R4.1, R5.1, R7.1, R14.2, R15.1, R17.1, R20.1, R31.1, R32.1, R33.1, R34.1, R35.1, R38.2, R51.1, R55.1, R60.1, RF3.2, RF4.2, RF4.3, SW18.2, SW18.4 (A), TP10.1, U1.2 (GND), U2.4, U2.9, U3.4 (~CE), U3.5 (EN2), U3.8 (VSS), U3.14 (TMR), U3.17 (VSS), U4.4 (GND), U4.9 (EXP), U5.3 (GND), U5.11 (GND), U5.15 (GND), U5.17 (PAD), U6.1 (GND), U6.9 (EPAD), U7.2 (GND), U8.7 (GND), U9.2 (GND), U10.2 (GND), U10.5 (GND), U10.8 (GND), U10.20 (GND), U10.25 (GND), U12.1 (GND), U12.7 (GND), U12.13 (GND), U12.15 (GND), U12.20 (GND), U12.25 (GND), U12.30 (GND), U12.34 (GND), U12.36 (GND), U12.38 (GND), U12.39 (GND), U12.40 (GND), U12.41 (GND), U12.43 (GND), U12.46 (GND), U12.51 (GND), U12.55 (GND), U12.60 (GND), U12.66 (GND), U12.71 (GND), U12.76 (GND), U12.105 (GND), U12.106 (GND), U12.107 (GND), U12.108 (GND), U12.109 (GND), U12.110 (GND), U12.111 (GND), U12.112 (GND), U12.113 (GND), U13.74 (VSS), U13.B7 (VSS), U14.3 (PGND), U14.7 (PS/SYNC), U14.9 (GND), U14.11 (PGND), X1.2 (GND), X1.4 (GND), X2.2, X2.4
unnamed: ANT1.1 (FEED), C88.1, L19.2
unnamed: ANT2.1 (FEEDING_POINT), L4.1
unnamed: C30.2, L1.2, L4.2, R3.1, RF3.1
unnamed: C80.2, C81.1, L15.2, L16.2, L17.1
unnamed: C81.2, C82.1, C83.1, L17.2
unnamed: C83.2, L18.1
unnamed: C87.1, L19.1, R6.2, RF4.1
unnamed: D4.2 (A), J5.2, Q4.3 (D)
unnamed: D5.2 (A), R19.2
unnamed: D6.2 (A), R21.2
unnamed: D7.2 (A), R22.2
unnamed: D8.2 (A), J6.2, Q7.3 (D)
unnamed: D9.2 (A), R23.2
unnamed: D10.2 (A), R24.2
unnamed: D11.2 (A), R25.2
unnamed: D12.2 (A), R26.2
unnamed: D13.2 (A), R27.2
unnamed: D17.1 (K), R52.2
unnamed: C14.1, C15.2, J2.1, R9.1
unnamed: C16.1, J7.2
unnamed: C94.1, J8.1 (In), R61.2
unnamed: J10.1, U5.9 (OUTP)
unnamed: J10.2, U5.10 (OUTN)
unnamed: C11.2, J11.1
unnamed: L5.1, L6.2
unnamed: C14.2, Q1.1 (B), R36.1
unnamed: Q5.3 (D), Q6.1 (G), R18.1
unnamed: Q5.1 (G), R16.2, R17.2
unnamed: Q6.3 (D), R19.1, R21.1, R22.1, R23.1, R24.1, R25.1, R26.1, R27.1
unnamed: R8.1, SW2.2
unnamed: SW18.1, SW18.3 (K), U9.1 (IN)
unnamed: C78.1, C79.2, U1.3 (RF1)
unnamed: C84.1, L18.2, U1.1 (RF2)
unnamed: R6.1, U1.5 (RFC)
unnamed: C86.1, R45.2, U1.4 (VC1)
unnamed: C85.1, R44.2, U1.6 (VC2)
unnamed: R4.2, U3.12 (ILIM)
unnamed: R5.2, U3.16 (ISET)
unnamed: R7.2, U3.1 (TS)
unnamed: R38.1, U5.2 (GAIN_SLOT)
unnamed: C21.2, R37.2, U5.4 (~SD_MODE)
unnamed: L3.2, U10.9 (DCC_SW)
unnamed: C78.2, L13.2, U10.22 (RFI_N)
unnamed: C75.2, L13.1, U10.21 (RFI_P)
unnamed: L15.1, U10.23 (RFO)
unnamed: C19.1, L3.1, U10.7 (VREG)
unnamed: C76.1, C77.1, L16.1, U10.24 (VR_PA)
unnamed: C8.1, U12.24 (DEC0)
unnamed: R12.2, U12.10 (ENABLE)
unnamed: R29.2, U12.59 (P0.03)
unnamed: R10.1, U12.3 (SWDCLK)
unnamed: R28.2, U12.4 (SWDIO)
unnamed: FB1.2, R12.1, U12.14 (VDD)
unnamed: C10.1, R13.2, U12.9 (~RESET)
unnamed: U9.5 (OUT), U14.6 (EN)
unnamed: L2.1, U14.4 (L1)
unnamed: L2.2, U14.2 (L2)
P0.16_COL_1: SW3.1, SW4.1, SW5.1, SW6.1, SW7.1, U13.AC11 (P0.16)
P0.17_COL_2: SW8.1, SW9.1, SW10.1, SW11.1, SW12.1, U13.AD12 (P0.17)
P0.19_COL_3: SW13.1, SW14.1, SW15.1, SW16.1, SW17.1, U13.AC15 (P0.19)
P1.01_ROW_1: R31.2, SW3.2, SW8.2, SW13.2, U13.Y23 (P1.01)
P1.02_ROW_2: R32.2, SW4.2, SW9.2, SW14.2, U13.W24 (P1.02)
P1.03_ROW_3: R33.2, SW5.2, SW10.2, SW15.2, U13.V23 (P1.03)
P1.04_ROW_4: R34.2, SW6.2, SW11.2, SW16.2, U13.U24 (P1.04)
P1.05_ROW_5: R35.2, SW7.2, SW12.2, SW17.2, U13.T23 (P1.05)
VBUS: C50.1, C89.1, J4.1, TP9.1, U3.6 (EN1), U3.13 (IN), U7.5 (VBUS), U13.AD2 (VBUS)
VSS_PA: C30.1, L1.1, NT3.2, RF3.3, U13.F23 (VSS_PA)
XC1: C22.1, U13.B24 (XC1), X2.3
XC2: C29.1, U13.A23 (XC2), X2.1
XL1: C31.2, U13.D2 (P0.00/XL1), X4.1
XL2: C32.2, U13.F2 (P0.01/XL2), X4.2

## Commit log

2026-01-23 First commit
    First commit, Libs are still a mess
    [3310_outline.dxf, AQFN-73_L7.0-W7.0-H0.9-P0.50.step, BUZ-SMD_4P-L8.5-W8.5-H3.0.step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]
2026-01-26 Adding testpoints
    Test pint on usb and SWD debug
    [Mesh3310.kicad_sch, mcu.kicad_sch]
2026-01-27 component placing
    component placing
    [Mesh3310.kicad_sch]
2026-01-27 Battery ic changes
    form Max1555 to BQ24074
    [power.kicad_sch]
2026-01-28 Cleaning and placing
    Cleaning and placing components
    [AQFN-73_L7.0-W7.0-H0.9-P0.50.step, BUZ-SMD_4P-L8.5-W8.5-H3.0.step, CONN-SMD_HCZZ0032-4.step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]
2026-01-30 Start of routing
    Component placing and start off routing
    [mcu.kicad_sch, rf.kicad_sch]
2026-01-31 backup work
    [rf.kicad_sch]
2026-02-01 RF designing
    [2450AT18A0100001E.step, Mesh3310.kicad_pcb, Mesh3310.kicad_sch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]
2026-02-02 cleanup
    schematic cleanup
    [Mesh3310.kicad_pcb, Mesh3310.kicad_sch, interfaces.kicad_sch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]
2026-02-03 Change antenna BT
    BT change
    [Mesh3310.kicad_pcb, Mesh3310.kicad_sch, mcu.kicad_sch]
2026-02-04 Lora changes
    Schematic changes to from RA to SOC
    [Mesh3310.kicad_pcb, Mesh3310.kicad_sch, rf.kicad_sch]
2026-02-04 Lora placement
    [Mesh3310.kicad_pcb, rf.kicad_sch]
2026-02-05 Lora antenna replacement
    Lora antenna replacement, added Nordic nRF 9151 for GPS , VoIP ,VoLTE-m , SIP
    [EG915UEUAC-N05-SNNSA.step, MX25R1635FZNIH0.step, Mesh3310.kicad_pcb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]
2026-02-11 Backing up work
    Backup work for today
    [Mesh3310.kicad_pcb, Mesh3310.kicad_sch, interfaces.kicad_sch]
2026-02-23 Backup work
    Adding some extra pads
    [Mesh3310.kicad_pcb, Mesh3310.kicad_sch, gnss.kicad_sch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]
2026-02-23 shematic changes
    small changes in NRF component
    [Mesh3310.kicad_pcb, mcu.kicad_sch, rf.kicad_sch]
2026-02-24 Schematic changes
    Adding gsm module , interfaces : mic+earspeaker
    [Mesh3310.kicad_pcb, Mesh3310.kicad_sch, SIM-ST-MFF2.step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]
2026-09-29 Schema afgemaakt, 6-laags layout, LCSC-onderdelen en productiebestanden
    - schema opgeschoond en aangevuld (ERC 0)
    - bord naar 6 lagen (JLC06161H-3313), volledig gerouteerd, DRC 0
    - LTE via U.FL, USB via bodemconnector J4
    - LCSC-nummers voor alle onderdelen, datasheets toegevoegd
    - gerbers, boorbestanden, positiebestand en stuklijst in productie/
    [Mesh3310-B_Cu.gbr, Mesh3310-B_Mask.gbr, Mesh3310-B_Paste.gbr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]
2026-09-29 README bijgewerkt, 3D-modellen compleet en nieuwe renders
    - README: actuele specificaties, projectstatus en mapindeling
    - ontbrekende en kapotte 3D-modelpaden gerepareerd
    - eenvoudige modellen voor nRF9151, SKY65723, antennes, ML414H en eSIM
    - renders van boven-, onderkant en 3D-aanzicht in afbeeldingen/
    [Mesh3310.kicad_pcb]
2026-10-17 PCB naar 4 lagen, 1,0 mm
2026-10-18 4 lagen 1,0 mm helemaal gerouteerd, productiebestanden rev. B
2026-10-18 4 lagen opnieuw vanaf main: alleen In4-netten rond de nRF52840 herlegd, rev. C-E erop, vulling opgeslagen
2026-10-20 Onderdelen die JLC niet had vervangen, JLC-uploadbestanden toegevoegd
